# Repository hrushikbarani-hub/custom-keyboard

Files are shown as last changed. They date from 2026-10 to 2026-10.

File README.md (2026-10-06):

# NEXUS 2x3 Wired Macro Pad

A compact six-key wired macro pad with a small I2C OLED screen.

## Design direction

- Layout: 2 rows x 3 columns, six MX-style keys
- Controller: Hack Club Orpheus Pico 2, USB-C, Pico-compatible footprint
- Display: Waveshare 0.91-inch OLED SKU 14657, SSD1306 128x32, GP4/GP5
- Firmware: USB HID macro layers
- PCB: custom KiCad board
- Case: two-piece 3D-printed case

## Initial layers

NEXUS: Wake PC, open NEXUS, display standby, microphone toggle, Jellyfin, Pi-hole/Tailscale status.

Media: previous, play/pause, next, volume down, volume up, mute.

## Build status

- [x] Concept, layout, pin budget, BOM, and grant draft
- [x] Confirm exact controller, OLED, switch, and socket part numbers
- [x] KiCad schematic (ERC clean)
- [x] PCB routing (DRC/connectivity/parity clean)
- [x] Case CAD (v1.1; physical fit pending)
- [x] Firmware source prepared
- [ ] Physical assembly and testing

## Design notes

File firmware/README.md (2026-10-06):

# NEXUS firmware

This is a CircuitPython starting firmware for the Orpheus Pico 2 and the routed NEXUS 2x3 matrix.

Copy `code.py` to the board after installing CircuitPython and the Adafruit HID library. The matrix assignment is:

- rows: GP6, GP7
- columns: GP8, GP9, GP10
- OLED: GP4 SDA, GP5 SCL, 3V3, GND

The six default actions are temporary placeholders: three desktop shortcuts followed by previous/play-next media controls. Edit `KEYMAP` after deciding the final macros.

Flashing still requires a USB data cable and the physical Orpheus Pico 2. Test one switch at a time after copying the file.

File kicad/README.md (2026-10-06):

# NEXUS 2x3 macro pad — KiCad 10

Open `NEXUS-MacroPad.kicad_pro`. Editable schematic, fully routed two-layer PCB, and project-local footprints are included. `manufacturing/` contains the two copper layers, both masks and silkscreens, board outline, and separate plated/non-plated Excellon drills. No solder-paste files are needed for this through-hole design.

## Fabrication and assembly

- PCB: 60 x 66 mm bounding box; chamfered outline with two OLED clamp reliefs. Two copper layers, 1.6 mm FR4, 0.25 mm traces/clearance, 0.8/0.4 mm vias. Order only after confirming the selected hardware dimensions.
- Six PCB-mount Cherry-MX-compatible switches, 19.05 mm pitch. Plate mounting supplies mechanical retention; switch solder joints locate the PCB. No independent PCB mounting screws are used.
- Six 1N4148 DO-35 diodes with 7.62 mm lead pitch. Cathode/band is the square pad and goes to the row. Front keys are SW1–3; rear keys SW4–6.
- Non-wireless Pico-compatible module socketed **under** the board, component side facing the case floor, USB facing the rear. Use two 1x20, 2.54 mm socket strips plus matching module headers. The host-board footprint courtyard describes socket rows, not the elevated underside module body. Do not install a Pico W: its antenna clearance is not provided.
- J1 is four direct-solder wire pads, not a header or a direct OLED-module footprint. Pin 1 GND, pin 2 3.3 V, pin 3 SCL, pin 4 SDA. Check the actual OLED pin order; use 3.3 V only. Solder insulated flexible leads directly to the pads and provide strain relief. Do not fit a vertical header: it would hit the lid. Keep solder/wire height below 1.2 mm above the PCB.
- R1 and R2 are optional 4.7k through-hole pullups on the PCB underside, marked DNP. Leave them empty if the display already has I2C pullups; populate only if needed. Top-side mounting would overlap the OLED envelope.
- Avoid long switch/diode leads on the underside where they approach the raised controller. Trim and inspect before inserting the module. Do not connect an external 5 V supply.

## Firmware pin assignment

| Function | GPIO | Pico physical pad |
|---|---|---|
| OLED SDA | GP4 | 6 |
| OLED SCL | GP5 | 7 |
| Front row ROW0 | GP6 | 9 |
| Rear row ROW1 | GP7 | 10 |
| Left column COL0 | GP8 | 11 |
| Middle column COL1 | GP9 | 12 |
| Right column COL2 | GP10 | 14 |

Scan rows low with column input pullups (COL2ROW). The schematic deliberately leaves unused module pins unconnected. Pico module ground pads are internally common; all seven carrier ground pads are also routed.

## Case compatibility and limits

Use the revised **v1.2** case in the [Onshape document](https://cad.onshape.com/documents/93b46cd1c225a7c1c0317dbe/w/328820a536ad539164365b4e/e/89c11f70e4b29e71ba5d3f40). The old v1 OLED bridge is superseded by two side clamps, which clear the PCB reliefs. Six underside diode pockets provide clearance after correcting the switch stack. Four printed bodies: base, plate, two clamps. Older case exports are superseded.

Case coordinates are front-left origin. PCB X = 100 + case X; PCB Y = 178 - case Y. Assembled PCB top is case Z = 21 mm, bottom 19.4 mm; the plate top is Z = 26 mm, and the local underside Z = 24.5 mm. MX seating uses 5 mm from plate TOP to PCB top (3.5 mm below the 1.5 mm clip region). STEP uses XY aligned to the case and requires a +21 mm Z translation. The earlier 19.5/17.9 mm stack was incorrect and is superseded. See the [Cherry mechanical drawing](https://www.farnell.com/datasheets/1792245.pdf), mounting options on page 2.

The STEP uses a generic Raspberry Pi Pico, not the exact USB-C Orpheus board. Installed MX switch 3D models are missing; their native footprint geometry is present. Onshape now checks the exact PCB outline plus 20 nominal electronics envelopes against the case and each other. The USB-plug/controller bounding-box overlap is intentionally excluded because a plug engages the connector; exact connector mating is not modeled. Nominal checks passed, but these are not a tolerance analysis or an exact component assembly. Actual socket height, USB plug, OLED module, switch variant, and insert pilot still require confirmation. No physical prototype has been tested. Toggle 'Show electronics fit envelopes' in the case feature to inspect; keep it OFF for printing/exporting case parts.

KiCad ERC, DRC, connectivity, and schematic-to-PCB parity reports are included. No reported issues were suppressed to obtain a pass. Manufacturing exports are design outputs, not an instruction to order without the above checks.

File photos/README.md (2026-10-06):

# NEXUS case v1.2

[Editable Onshape case](https://cad.onshape.com/documents/93b46cd1c225a7c1c0317dbe/w/328820a536ad539164365b4e/e/89c11f70e4b29e71ba5d3f40).

The document contains four printable bodies: base, top plate, and two OLED side clamps. Download the stored tabs `NEXUS-case-v1.2.step` and `NEXUS-case-v1.2-print-parts.zip`. The ZIP contains separate binary STL parts in millimetres, Fine resolution. Older v1/v1.1 exports and the legacy notes are superseded; do not print those versions.

The custom case feature includes 'Show electronics fit envelopes'. It is OFF for fabrication exports. Enable it for inspection only: the extra bodies are nominal clearance envelopes, not real components or printable parts. The feature automatically checks interference before removing/hiding those bodies. See [FIT-CHECK.md](FIT-CHECK.md) for corrections, checks, and limitations.

## Key dimensions

- Enclosure: 76 x 78 x 26 mm; walls 3 mm; floor 2.4 mm.
- Six MX centers: X=18.95,38,57.05; Y=19,38.05; pitch 19.05 mm.
- Default switch opening: 14.1 mm square. Local plate thickness: 1.5 mm.
- Plate top Z=26; local underside Z=24.5; PCB top/bottom Z=21/19.4. The earlier PCB stack was 1.5 mm too low.
- OLED window: 32 x 10.5 mm; module pocket: 40 x 15.5 mm, centered at (38,60.5). Pocket ceiling Z=24.5. Actual module fit is not confirmed.
- Clamp screw centers: (14,60.5),(62,60.5); clamp top Z=18.2. Choose gentle nonconductive foam for the actual OLED stack; do not compress glass or electronics.
- Four M3 case posts: X=6.5/69.5, Y=6.5/71.5; insert pilot diameter defaults to 4.2 mm and MUST match the insert supplier's recommended hole.
- Rear cable slot: 16 mm wide, bottom Z=5. Exact cable housing/connector alignment still needs confirmation.

## Assembly

Trial-print a switch opening and insert hole first. Print the base floor down, plate outer face down, and clamps flat; drop exported parts to the slicer bed because they retain assembly coordinates. Install inserts; clip switches into the plate; solder the PCB at the correct switch seating height. Install the underside controller sockets/module and trim leads carefully. Fit optional underside pullups only if needed. Solder low-profile insulated OLED wires directly to J1: no vertical header. Retain the OLED using the two clamps, foam, and M2x8 screws. Verify all clearances and USB cable access before closing with four M3x16 screws. Optional foot recesses suit approximately 8 mm adhesive feet.

This is not a fabrication release. Exact component dimensions, lead/solder clearances, printing tolerances, and physical fit remain unverified. Firmware and physical testing remain outstanding.

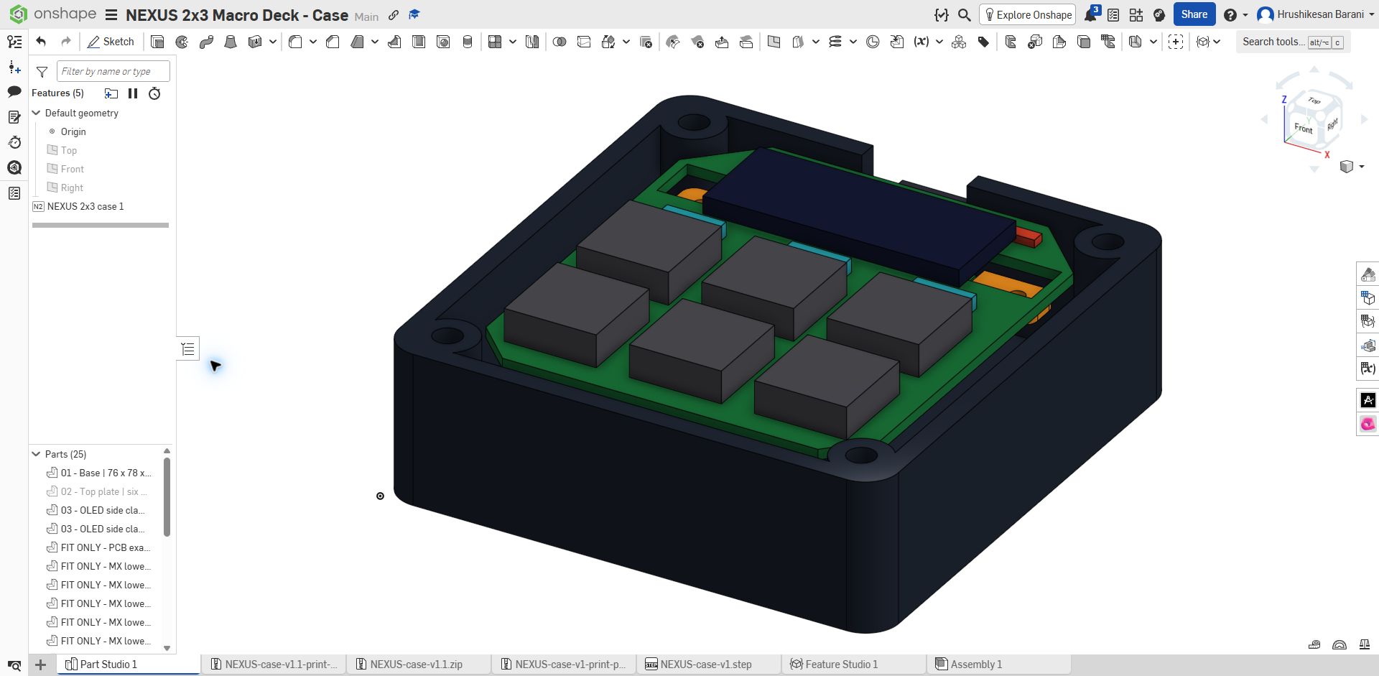
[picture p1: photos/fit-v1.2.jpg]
Nominal fit with plate hidden


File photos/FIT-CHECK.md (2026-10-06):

# NEXUS nominal fit check — v1.2

This is a CAD-envelope check, not a release for fabrication or a physical validation. The computer-use workflow added a permanent Onshape fit-preview parameter and regeneration checks; the PDF workflow exposed the incorrect switch stack using the manufacturer's mechanical drawing.

## Corrections

1. PCB top moved from case Z=19.5 to 21 mm. Standard Cherry MX lower housing height is 5 mm from flange/plate top to PCB top, not from plate underside. Plate top Z=26; local 1.5 mm plate underside Z=24.5; PCB bottom Z=19.4.
2. Six diode clearance pockets added beneath the plate, leaving 1.5 mm local plate thickness and pocket ceiling Z=24.5.
3. Vertical OLED header eliminated. J1 retains the same four through-hole pads with a wire-pad footprint and no header model. Use direct-solder flexible leads, with maximum 1.2 mm protrusion above PCB; strain relief is needed.
4. Optional R1/R2 moved to the PCB underside, outside the controller/socket envelope, to avoid overlap with the lid-mounted OLED. They remain DNP by default.

## CAD checks executed

The native case feature generated four printable case bodies plus 21 fit-only bodies: exact PCB outer contour/cutouts, six MX lower-housing envelopes, six diode envelopes, two resistor envelopes, controller component envelope, two socket envelopes, USB-plug envelope, OLED envelope, and wire-pad envelope. It checks all these bodies against the case, plus all fit-body pairs. Interior interference or containment throws a regeneration error. Face contact is allowed. Regeneration succeeded with fit visibility both ON (25 bodies) and OFF (four printable bodies).

The controller/USB-plug envelope pair is deliberately excluded: their bounding boxes overlap at connector engagement. Actual mating shapes, insertion travel, cable bending, solder tails, switches' retaining clips/pins, keycap profiles, and printing/component tolerances are not modeled. Fit-only bodies are not manufacturer STEP models.

## Nominal clearances

| Location | Nominal clearance |
|---|---:|
| Diode envelope to relieved plate ceiling | 1.3 mm |
| Wire-pad envelope to lid underside | 0.8 mm |
| OLED envelope to PCB top | 0.8 mm |
| Clamp to nearest PCB relief boundary | 0.5 mm |
| Controller envelope to floor | 6.1 mm |

These depend on the provisional dimensions and exclude tolerance accumulation. The generic USB envelope is 14 mm wide within a 16 mm case slot; exact Orpheus connector/cable fit remains unverified.

## Electrical verification

After rerouting the underside pullups and replacing J1's footprint: zero reported ERC violations, zero reported DRC violations, zero unconnected items, zero schematic/PCB parity issues. Reports, updated Gerbers and drills are in the KiCad deliverables.

## Still required

- Product links or measured dimensions for the actual controller, sockets, OLED, switches, and USB data cable.
- Confirm insert manufacturer's required pilot diameter, and trial-print one switch cutout and insert hole.
- Replace provisional envelopes with actual component models where available and verify tolerances/lead trimming.
- Write/build/flash firmware and test the physical assembly.
- Download the v1.2 case exports from Onshape; old v1/v1.1 exports are superseded.
- Confirm Keeb accepts a six-key, AI-assisted macro pad before committing grant funds. No organizer has been contacted or application submitted.

Mechanical source: [Cherry MX manufacturer's drawing, page 2](https://www.farnell.com/datasheets/1792245.pdf).

Nominal electronics fit with plate hidden

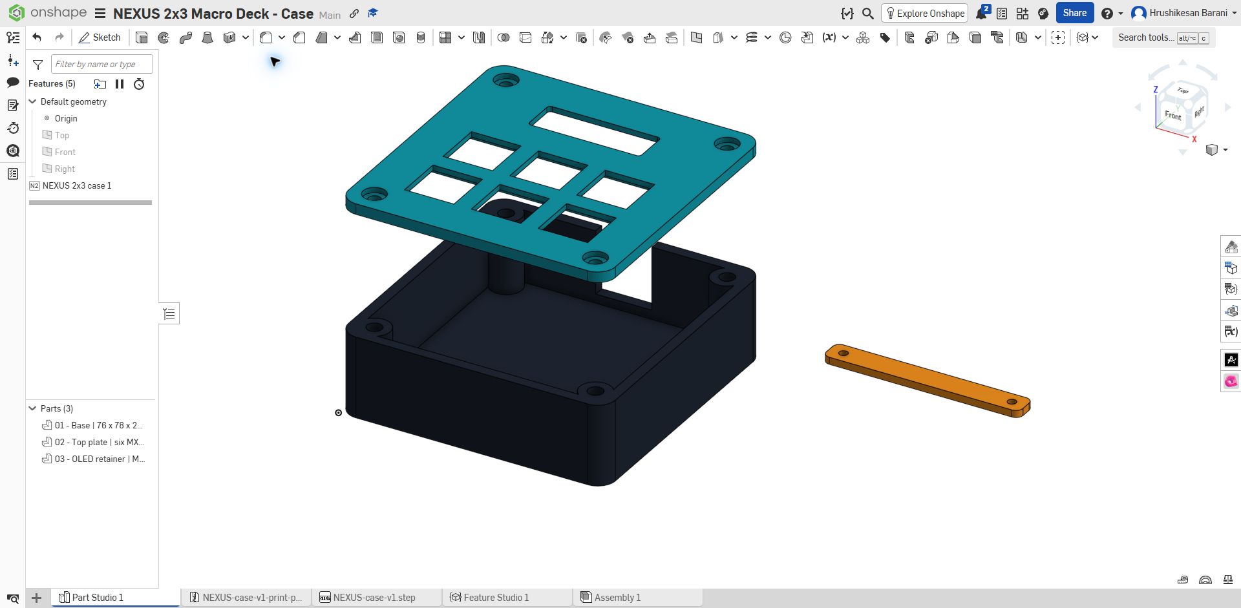
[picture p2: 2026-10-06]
photos/exploded.jpg

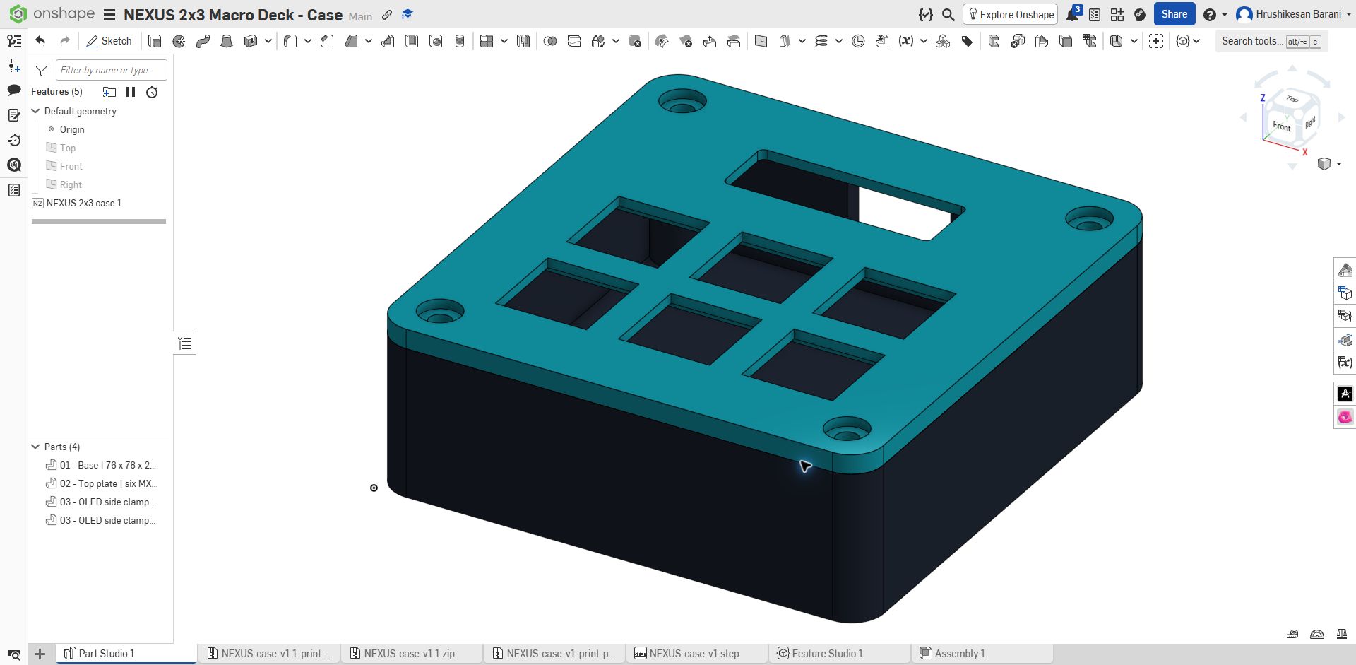
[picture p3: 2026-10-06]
photos/case-v1.1.jpg

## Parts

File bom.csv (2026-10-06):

Item | Qty | Specification | Purpose | Status | Notes
Orpheus Pico 2 | 1 | Hack Club Orpheus Pico 2 RP2040 USB-C controller | USB HID brain | Selected | Identical Pico footprint; USB-C rear
Cherry MX2A Black MX2A-11NB | 6 | 5-pin PCB-mount linear black switch | Six keys | Selected | PCB footprint includes both plastic locating pins
DSA keycap | 6 | MX-compatible 1u | Key tops | Request | Uniform profile
1N4148 through-hole diode | 6 | DO-35 7.62 mm | Matrix anti-ghosting | Request | One per switch
Waveshare 0.91 inch OLED SKU 14657 | 1 | SSD1306 128x32 white I2C 36x12.5 mm | Status screen | Selected | PH2.0 cable required; wire by signal not connector position
Custom PCB | 1 | 2x3 matrix with OLED header | Electrical assembly | Fabrication | Generate after DRC
Case and top plate | 1 | Base plus plate plus two OLED side clamps | Enclosure | Fabrication | Use v1.2 STEP and STL exports
M3x16 mm screw | 4 | M3 stainless or equivalent | Case assembly | Request | Final count depends on case
M3 heat-set insert | 4 | M3x5x4 mm | Threaded case mount | Request | Final count depends on case
USB-C data cable | 1 | USB 2.0 data capable | Connect keyboard | Request | Not charge-only
Solder and hookup wire | 1 | Assembly supplies | Build and repair | Optional | May already be available
Adafruit 5583 Pico socket headers | 2 | 1x20 female 2.54 mm | Underside controller mounting | Selected | Kit supplies two socket strips
Adafruit 5584 short male headers | 2 | 1x20 male 2.54 mm | Controller mating pins | Selected | Use if Orpheus has no headers
M2 screw | 2 | M2x8 suitable for 1.7 mm plastic pilots | OLED side clamps | Required | Do not substitute longer screws
Foam pad | 1 | Nonconductive compressible pad cut to suit OLED | OLED retention | Required | Do not press on glass or components
Rubber foot | 4 | Approximately 8 mm adhesive foot | Desk grip | Optional | Base recesses 8.2 mm diameter
4.7k resistor | 2 | Axial DIN0207 7.62 mm lead pitch | Optional I2C pullups | DNP | Fit underside only if OLED lacks pullups

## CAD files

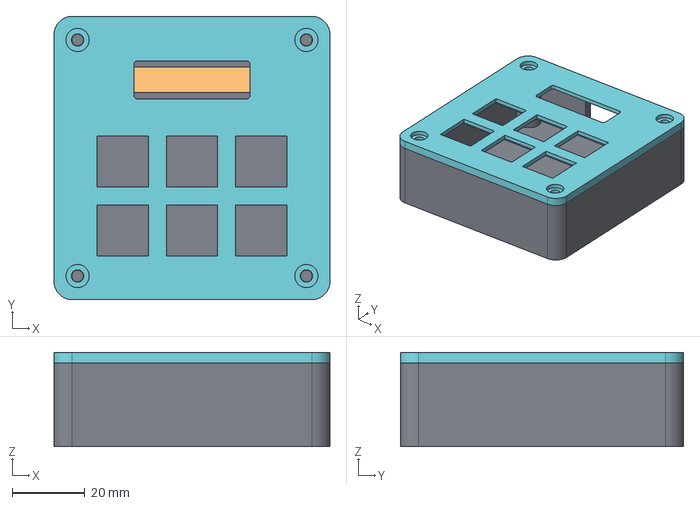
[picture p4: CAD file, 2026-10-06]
case/NEXUS-case.step
76.0 x 78.0 x 26.0 mm

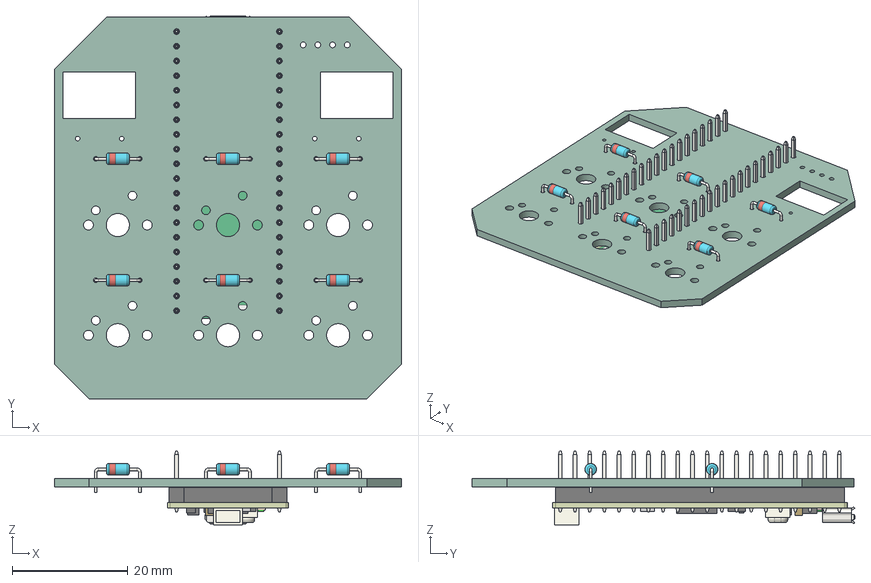
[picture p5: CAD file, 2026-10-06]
kicad/NEXUS-MacroPad.step
60.0 x 66.2 x 12.8 mm
D_DO-35_SOD27_P7.62mm_Horizontal x 6
RaspberryPi_Pico_H_Module_KiCad
RaspberryPi_Pico_Header_DIP-40_H2.54mm_KiCad
NEXUS-MacroPad_PCB

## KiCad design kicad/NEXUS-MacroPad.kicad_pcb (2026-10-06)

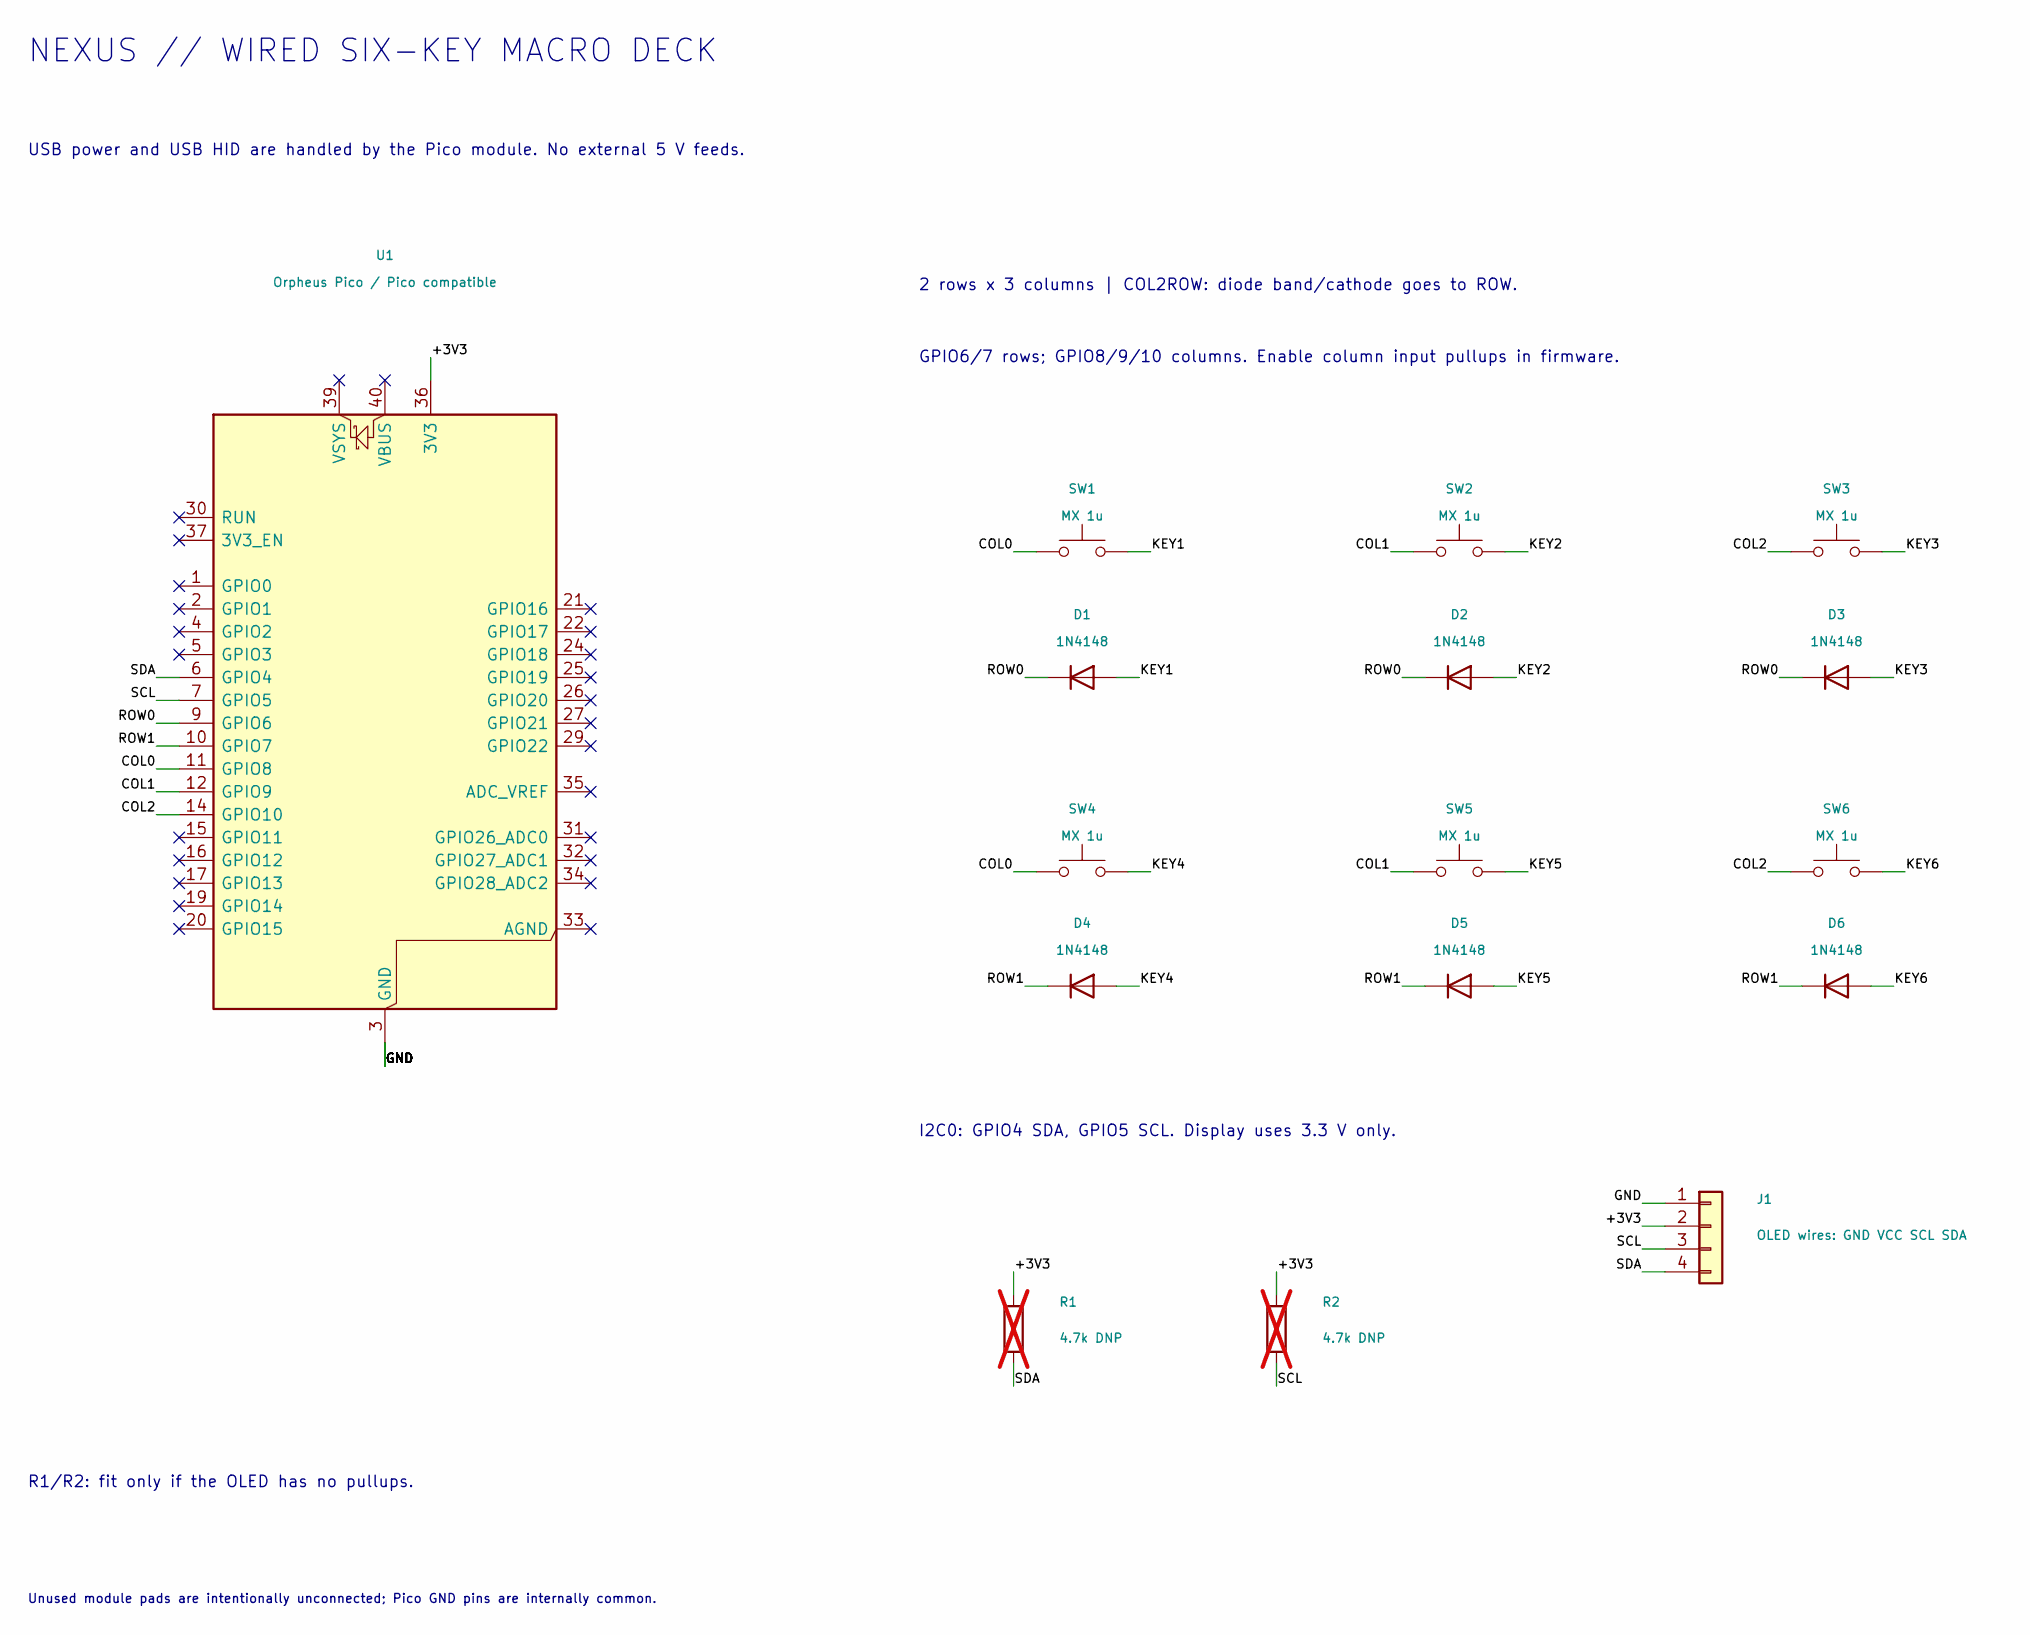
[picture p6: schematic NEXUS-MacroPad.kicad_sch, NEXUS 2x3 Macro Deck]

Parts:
D1, D2, D3, D4, D5, D6: 1N4148; D_1N4148
J1: OLED wires: GND VCC SCL SDA; OLED_WirePads
R1, R2: 4.7k DNP; R_Axial_DIN0207_L6.3mm_D2.5mm_P7.62mm_Horizontal; not fitted
SW1, SW2, SW3, SW4, SW5, SW6: MX 1u; MX_1u
U1: Orpheus Pico / Pico compatible; Pico_Underside_Carrier

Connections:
/+3V3: J1.2, R1.1, R2.1, U1.36 (3V3)
/COL0: SW1.1, SW4.1, U1.11 (GPIO8)
/COL1: SW2.1, SW5.1, U1.12 (GPIO9)
/COL2: SW3.1, SW6.1, U1.14 (GPIO10)
/GND: J1.1, U1.3 (GND), U1.8 (GND), U1.13 (GND), U1.18 (GND), U1.23 (GND), U1.28 (GND), U1.38 (GND)
/KEY1: D1.2 (A), SW1.2
/KEY2: D2.2 (A), SW2.2
/KEY3: D3.2 (A), SW3.2
/KEY4: D4.2 (A), SW4.2
/KEY5: D5.2 (A), SW5.2
/KEY6: D6.2 (A), SW6.2
/ROW0: D1.1 (K), D2.1 (K), D3.1 (K), U1.9 (GPIO6)
/ROW1: D4.1 (K), D5.1 (K), D6.1 (K), U1.10 (GPIO7)
/SCL: J1.3, R2.2, U1.7 (GPIO5)
/SDA: J1.4, R1.2, U1.6 (GPIO4)

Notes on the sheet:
NEXUS // WIRED SIX-KEY MACRO DECK
USB power and USB HID are handled by the Pico module. No external 5 V feeds.
2 rows x 3 columns | COL2ROW: diode band/cathode goes to ROW.
GPIO6/7 rows; GPIO8/9/10 columns. Enable column input pullups in firmware.
I2C0: GPIO4 SDA, GPIO5 SCL. Display uses 3.3 V only.
R1/R2: fit only if the OLED has no pullups.
Unused module pads are intentionally unconnected; Pico GND pins are internally common.

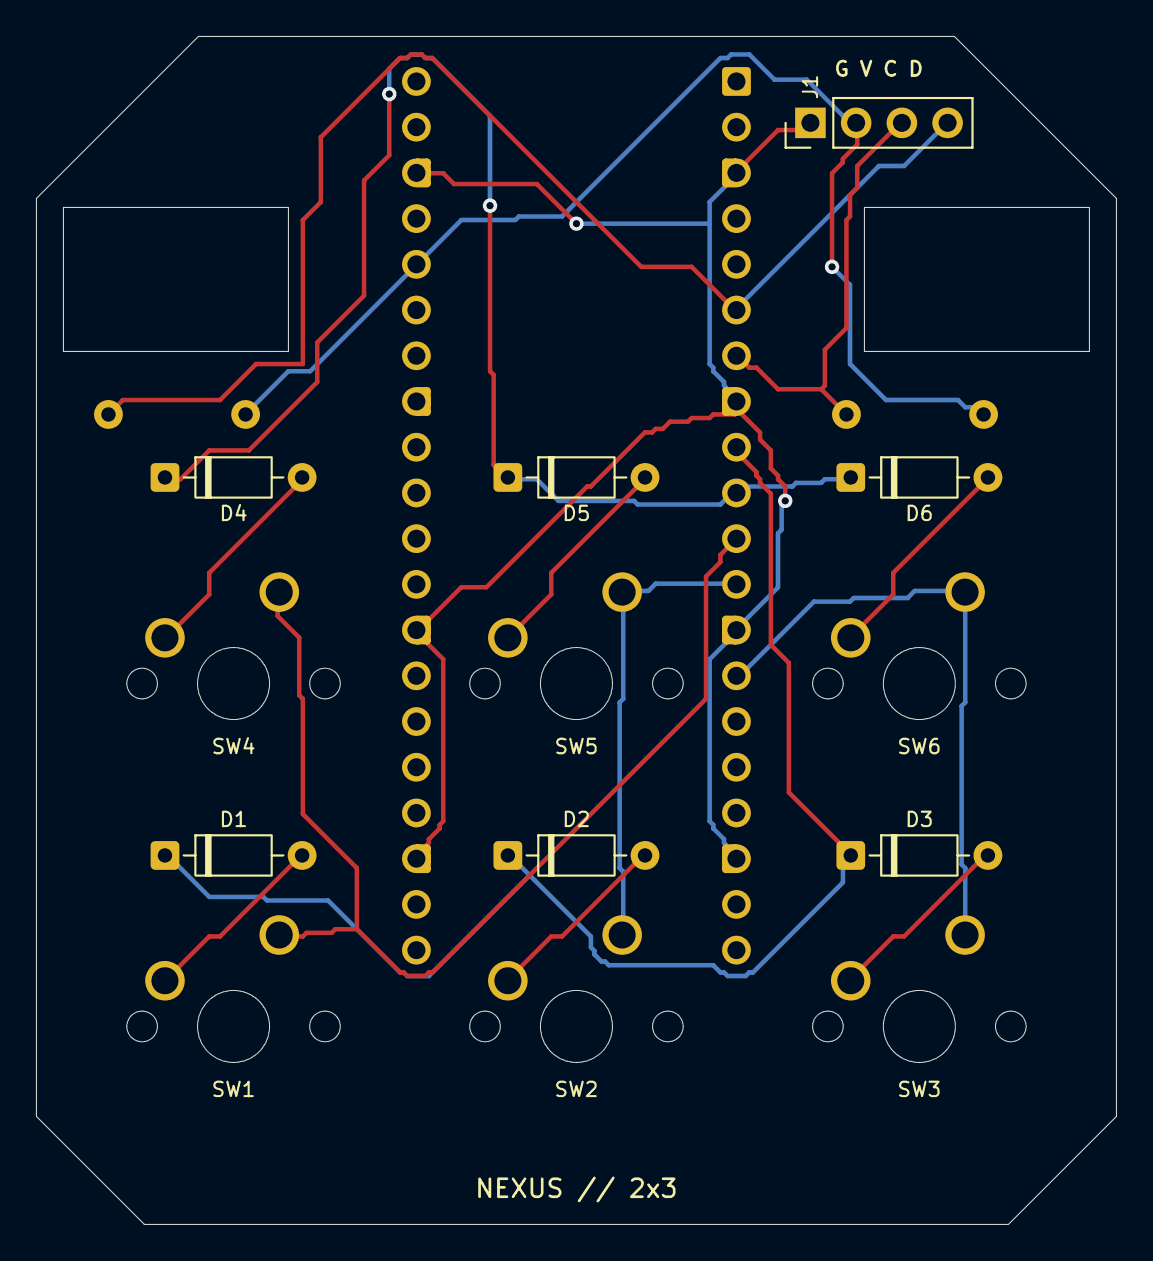
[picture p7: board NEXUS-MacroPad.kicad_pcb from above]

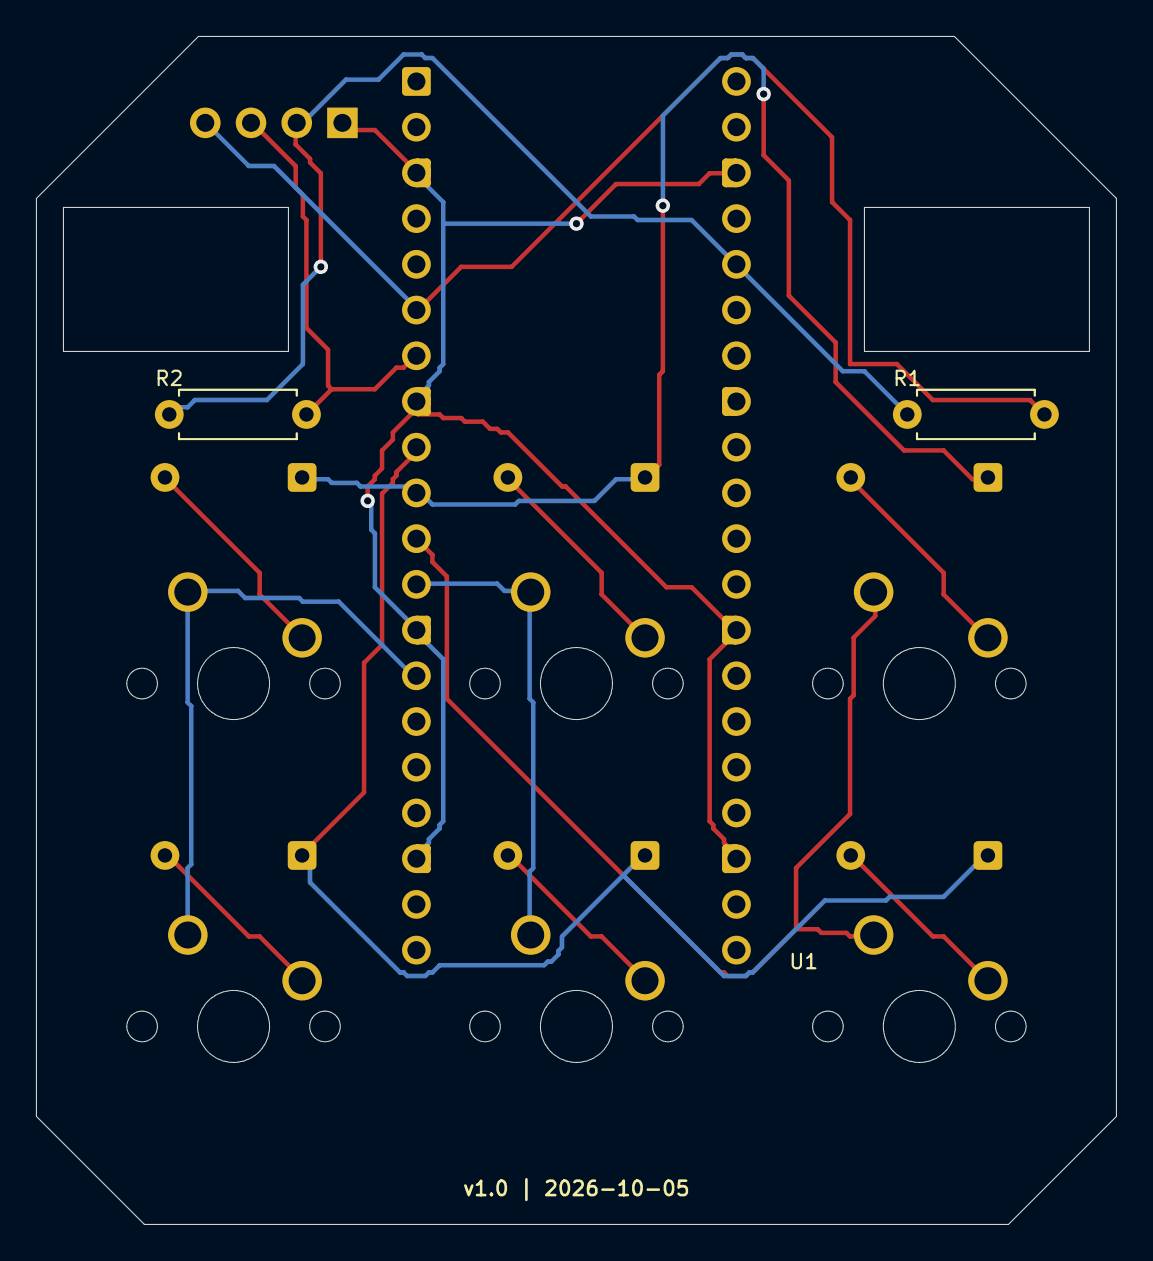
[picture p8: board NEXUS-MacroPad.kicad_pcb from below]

Board: 2 copper layers, 60.0 x 66.0 mm, 16 parts (3 on the bottom side), 15 nets.

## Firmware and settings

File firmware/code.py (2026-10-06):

import time
import board
import busio
import digitalio
import usb_hid
from adafruit_hid.keyboard import Keyboard
from adafruit_hid.keycode import Keycode
from adafruit_hid.consumer_control import ConsumerControl
from adafruit_hid.consumer_control_code import ConsumerControlCode

# NEXUS 2x3 COL2ROW matrix, matching the KiCad pinout.
ROWS = (board.GP6, board.GP7)
COLS = (board.GP8, board.GP9, board.GP10)

row_pins = []
for pin in ROWS:
    io = digitalio.DigitalInOut(pin)
    io.direction = digitalio.Direction.OUTPUT
    io.value = True
    row_pins.append(io)

col_pins = []
for pin in COLS:
    io = digitalio.DigitalInOut(pin)
    io.direction = digitalio.Direction.INPUT
    io.pull = digitalio.Pull.UP
    col_pins.append(io)

keyboard = Keyboard(usb_hid.devices)
consumer = ConsumerControl(usb_hid.devices)

# Replace these actions with the user's final macro choices.
KEYMAP = (
    (("key", (Keycode.CONTROL, Keycode.ALT, Keycode.T)),),
    (("key", (Keycode.CONTROL, Keycode.ALT, Keycode.N)),),
    (("key", (Keycode.CONTROL, Keycode.ALT, Keycode.M)),),
    (("consumer", ConsumerControlCode.PREVIOUS_TRACK),),
    (("consumer", ConsumerControlCode.PLAY_PAUSE),),
    (("consumer", ConsumerControlCode.NEXT_TRACK),),
)

last = [False] * 6

def press_action(index):
    kind, action = KEYMAP[index][0]
    if kind == "consumer":
        consumer.send(action)
        return
    for key in action:
        keyboard.press(key)
    keyboard.release_all()

while True:
    for r, row in enumerate(row_pins):
        row.value = False
        time.sleep(0.0005)
        for c, col in enumerate(col_pins):
            index = r * len(col_pins) + c
            down = not col.value
            if down and not last[index]:
                press_action(index)
            last[index] = down
        row.value = True
    time.sleep(0.001)
